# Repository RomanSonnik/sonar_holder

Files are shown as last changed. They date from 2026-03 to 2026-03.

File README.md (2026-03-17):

# Sonar using two HC-SR04 and Arduino UNO R3

This project was made by two students from RTU (Riga Technical University) in 2026 as a course project.
The repo contains all the information needed to assemble a similar unit yourself.

https://github.com/user-attachments/assets/edb18fed-01fb-47a9-b66d-83d6e0534f34

Project was inspired by Alex Gyver "[Aim-Fan (MOS DUAL VERSION)](https://github.com/AlexGyver/Aim-Fan/tree/master)"
As it is under the MIT license, we took the original code and modified it for our project.

# Part list
| Part name  | Quantity |
| :---: | :---: |
| Arduino UNO R3 (or analog)  | 1  |
| Red LED  | 1  |
| HC-SR04  | 2  |
| Switch | 1 |
| 1 kOhm Resistor | 1 |
| Breadboard | 1 |
| Holder for 4x AA batteries | 1 |
| Servo motor 18,3kg/cm (6V) 180° | 1 |
| Jumper wires | many |

# Shematics



The provided schematic shows how to assemble all parts together.
In this modification you need to power the Arduino separately using a 5V USB power supply.
It can be changed to use only batteries, but it may cause possible MCU instability.

If you want to use the second variant, here is the schematic:



# Instructions

The main part for assembly is the main platform. It can be 3D printed or cut from wood.
Other parts are mainly made for aesthetics and can be replaced with simpler constructions.
By default, your device should look something like this:





**Note:** This is a reference design only, so in your variant the part layout may be different.

# Libraries
**Attention:** To use this code, you should install **all libraries** from the `libraries` folder. Otherwise, the code won't work.

# Main variables

This is the only place where you should change any settings.
You can try many combinations to get the desired output reliability and distance.

```
// ------------- SETTINGS --------------
#define STEP_DELAY 25       // SPEED OF SERVO
#define TIMEOUT 650        // TIME OUT BEFORE NEW SEEK
#define MAX_ANGLE 180       // MAXIMAL ROTATION ANGLE
#define MIN_ANGLE 0        // MINIMAL ROTATION ANGLE
#define DIST_MAX 200        // MAX DISTANCE CAP
#define DEADZONE 20         // MINIMAL DIFFERENCE WITH CALIBRATION
#define MIN_CATCH 15         // MIN POINTS TO COUNT AS TARGET
#define MISTAKES 5          // MISTAKES THAT SISTEM IGNORES DURING SCAN
// ------------- SETTINGS --------------

// ---------- PINS ----------
#define TRIG 4
#define ECHO 5
#define TRIG2 7
#define ECHO2 6

#define SERVO 9
#define MOS 10
// ---------- PINS ----------
```
At this point, if everything is assembled correctly and the preferences are set properly, you should have a working device.

# Contributions

This project is licensed under the MIT license, which means you can use, modify, sell, etc., without any fees.

Feel free to share your opinion in the Issues section or create pull requests.
If there are really good improvements, we will merge them with proper credit.

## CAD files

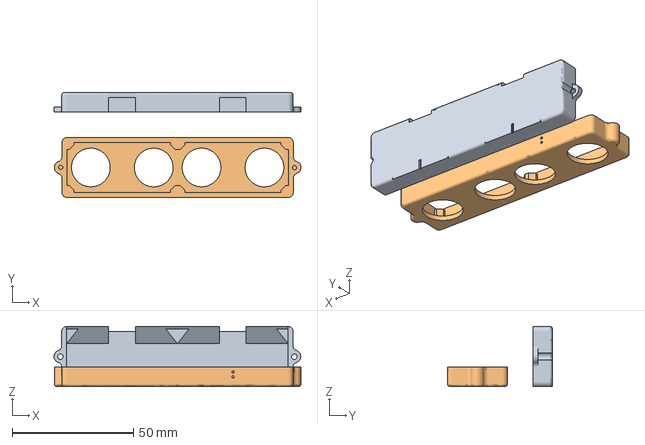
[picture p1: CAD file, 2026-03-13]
models/Ultrasonic sensor.3mf
102.1 x 43.4 x 24.8 mm
Assembly x 2

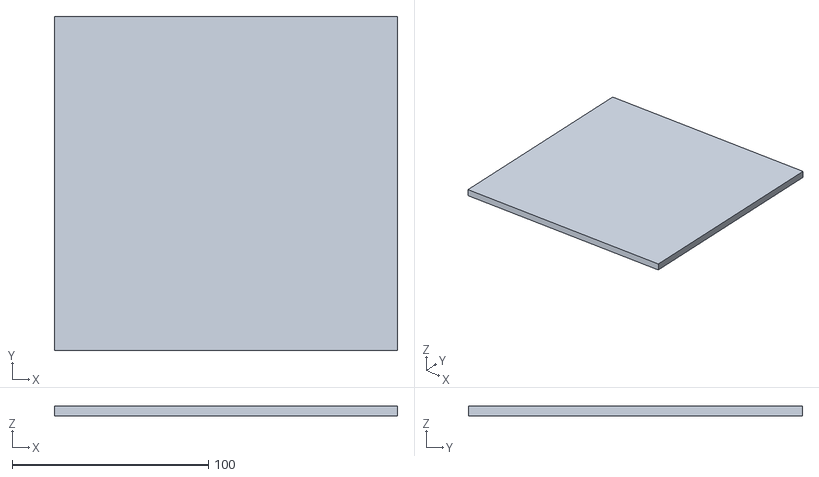
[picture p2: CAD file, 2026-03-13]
models/platform.stl
174.7 x 170.0 x 5.00

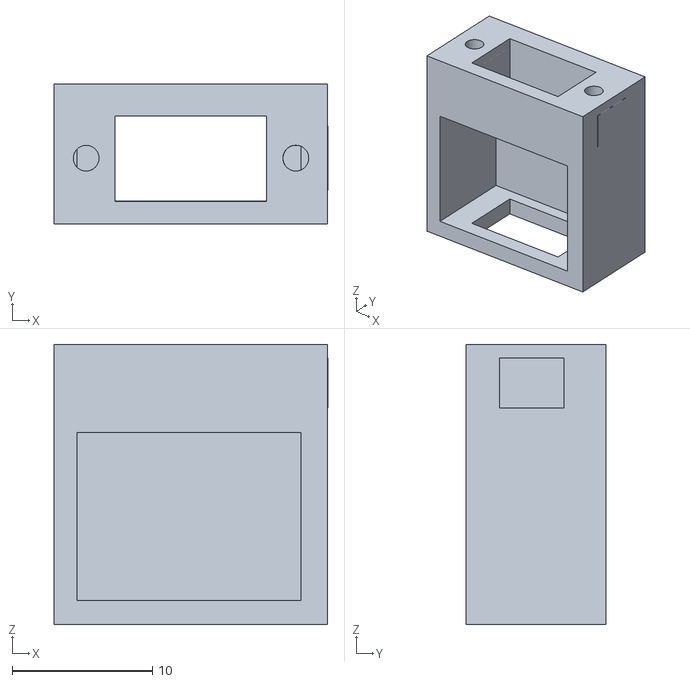
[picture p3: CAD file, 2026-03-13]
models/Switch holder.stl
19.6 x 10.0 x 20.0

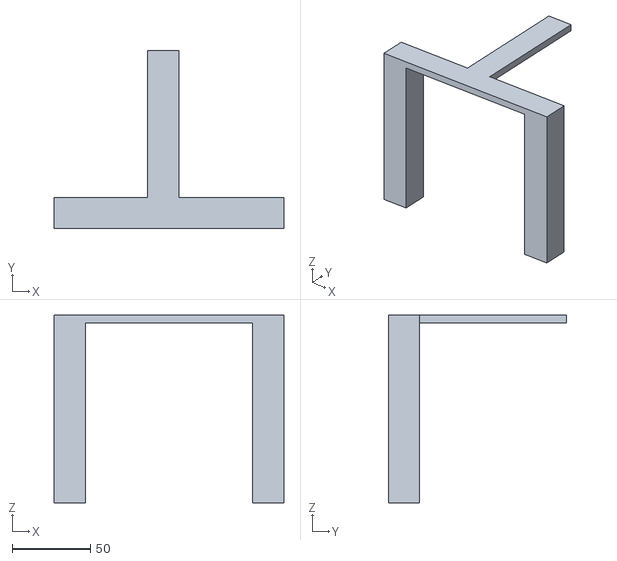
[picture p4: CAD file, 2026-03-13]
models/arc.stl
147.0 x 114.0 x 120.0

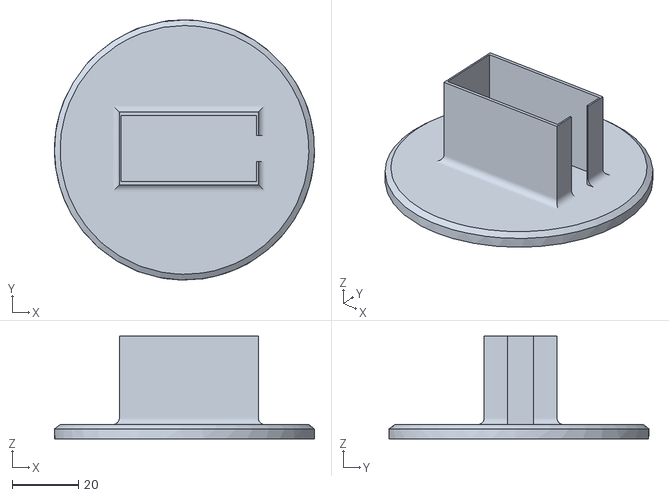
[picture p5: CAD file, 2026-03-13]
models/Servo holder.stl
78.6 x 78.6 x 31.0

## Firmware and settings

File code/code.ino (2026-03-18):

// ------------- SETTINGS --------------
#define STEP_DELAY 25       // SPEED OF SERVO
#define TIMEOUT 650        // TIME OUT BEFORE NEW SEEK
#define MAX_ANGLE 180       // MAXIMAL ROTATION ANGLE
#define MIN_ANGLE 0        // MINIMAL ROTATION ANGLE
#define DIST_MAX 200        // MAX DISTANCE CAP

#define DEADZONE 20         // MINIMAL DIFFERENCE WITH CALIBRATION
#define MIN_CATCH 15         // MIN POINTS TO COUNT AS TARGET
#define MISTAKES 5          // MISTAKES THAT SISTEM IGNORES DURING SCAN
// ------------- SETTINGS --------------

// ---------- PINS ----------
#define TRIG 4
#define ECHO 5
#define TRIG2 7
#define ECHO2 6

#define SERVO 9
#define MOS 10
// ---------- pins ----------


#include "Servo.h"
Servo servo;

#include "GyverHacks.h"
GTimer stepTimer(STEP_DELAY);
GTimer sonarTimer(50);
GTimer timeoutTimer(TIMEOUT);

#include <NewPing.h>
NewPing sonar1(TRIG, ECHO, DIST_MAX);
NewPing sonar2(TRIG2, ECHO2, DIST_MAX);

typedef enum {SEEK, HOLD};
boolean direct;
boolean next;
const byte steps_num = (MAX_ANGLE - MIN_ANGLE);
int angle = MIN_ANGLE;
int distance1[steps_num + 1], distance2[steps_num + 1];
boolean catch_flag, catched_flag, hold_flag = false;
byte catch_num;
byte mistakes;
byte mode = 0;
byte catch_pos;
int hold_signal;
byte direct_seek = 2;
byte lost_flag = 0;


void setup() {
  Serial.begin(115200);
  servo.attach(SERVO);
  servo.write(MIN_ANGLE);
  pinMode(MOS, OUTPUT);
  delay(5000);
  digitalWrite(MOS, 0);
  delay(3000);            
  calibration();          
}

void loop() {
  switch (mode) {
    case SEEK: seek();  
      break;
    case HOLD: hold();  
      break;
  }
}

void seek() {
  if (direct) {             
    if (angle < MAX_ANGLE)
      turn_to(MAX_ANGLE);   
    else {
      direct = false;       
      delay(50);            
    }
  }
  else {                    
    if (angle > MIN_ANGLE)
      turn_to(MIN_ANGLE);   
    else {
      direct = true;        
      delay(50);            
    }
  }
  search();                 
}

void hold() {
  if (!hold_flag) {       
    turn_to(catch_pos);     
  } else {                    
    digitalWrite(MOS, 1);
    if (sonarTimer.isReady()) {                   
      byte pos = (angle - MIN_ANGLE);         
      int curr_dist1, curr_dist2;
      int diff1, diff2;

      curr_dist1 = sonar2.ping_cm(); 
      if (curr_dist1 == 0) curr_dist1 = DIST_MAX;   
      diff1 = distance1[pos] - curr_dist1;          
      delay(50);
      curr_dist2 = sonar1.ping_cm();   
      if (curr_dist2 == 0) curr_dist2 = DIST_MAX;   
      diff2 = distance2[pos] - curr_dist2;          

      if (lost_flag == 0) {
        if (diff1 < DEADZONE) {
          direct_seek = 1;
          lost_flag = 1;
        }
        if (diff2 < DEADZONE) {
          direct_seek = 0;
          lost_flag = 1;
        }
      } else if (lost_flag == 1) {
        if (diff1 < DEADZONE && diff2 < DEADZONE) lost_flag = 2;
      }

      if (diff1 > DEADZONE && diff2 > DEADZONE) {
        lost_flag = 0;
      }

      if (lost_flag == 2) {   
        if (timeoutTimer.isReady()) {             
          mode = SEEK;                            
          hold_flag = false;
          direct = direct_seek;
          lost_flag = 0;
          digitalWrite(MOS, 0);
        }
      } else {                                    
        timeoutTimer.reset();                     
      }
    }
  }
}

void search() {
  if (/*angle % 2 == 0 &&*/ next) {                 
    
    next = false;

    byte pos = (angle - MIN_ANGLE);         
    int curr_dist;
    int diff;

    if (direct) curr_dist = sonar2.ping_cm(); 
    else curr_dist = sonar1.ping_cm();

    if (curr_dist == 0) curr_dist = DIST_MAX;   

    if (direct) diff = distance1[pos] - curr_dist;         
    else diff = distance2[pos] - curr_dist;

    if (diff > DEADZONE) {                      
      if (!catch_flag) {
        catch_flag = true;        
        catch_pos = angle;        
      }
      catch_num++;                
      if (catch_num > MIN_CATCH)  
        catched_flag = true;      
    } else {                                    
      if (catch_flag) {               
        if (mistakes > MISTAKES) {    
          
          catch_flag = false;
          catched_flag = false;
          catch_num = 0;
          mistakes = 0;
        } else {
          mistakes++;                 
        }
      }

      if (catched_flag) {             
        mode = HOLD;                  
        
        if (direct) catch_pos += (catch_num / 2);
        else catch_pos -= (catch_num / 2);

        hold_flag = false;
        catch_flag = false;
        catched_flag = false;
        catch_num = 0;
        mistakes = 0;
      }
    }
  }
}

void calibration() {
  for (angle = MIN_ANGLE; angle <= MAX_ANGLE; angle++) {
    servo.write(angle);
    byte pos = (angle - MIN_ANGLE);
    int curr_dist = sonar2.ping_cm();
    if (curr_dist == 0) distance1[pos] = DIST_MAX;
    else distance1[pos] = curr_dist;
    delay(STEP_DELAY);
  }
  for (angle = MAX_ANGLE; angle >= MIN_ANGLE; angle--) {
    servo.write(angle);
    byte pos = (angle - MIN_ANGLE);
    int curr_dist = sonar1.ping_cm();
    if (curr_dist == 0) distance2[pos] = DIST_MAX;
    else distance2[pos] = curr_dist;
    delay(STEP_DELAY);
  }
}

void turn_to(byte to_angle) {
  if (stepTimer.isReady()) {
    if (angle < to_angle) angle++;
    else if (angle > to_angle) angle--;
    else {
      hold_flag = true;
    }
    servo.write(angle);
    next = true;
    if (angle > MAX_ANGLE) direct = false;
    if (angle < MIN_ANGLE) direct = true;
  }
}

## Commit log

2026-03-13 Added 3d models for case
    [Servo holder.stl, Switch holder.stl, arc.stl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]
2026-03-13 Added holder for ultrasonic sensor
    [Ultrasonic sensor.3mf]
2026-03-16 Replace schematic image with a new version
    Updated schematic image in the README.
2026-03-17 Update schematic images in README.md
2026-03-17 Replace schematic images with updated versions
    Updated schematic images in the README with new sources.
